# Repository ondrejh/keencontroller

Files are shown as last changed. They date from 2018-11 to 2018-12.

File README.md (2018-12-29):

# Keen Controller
Arduino micro based keyboard (mame controller) suitable for playing [Commander Keen](http://www.shikadi.net/keenwiki/Main_Page).

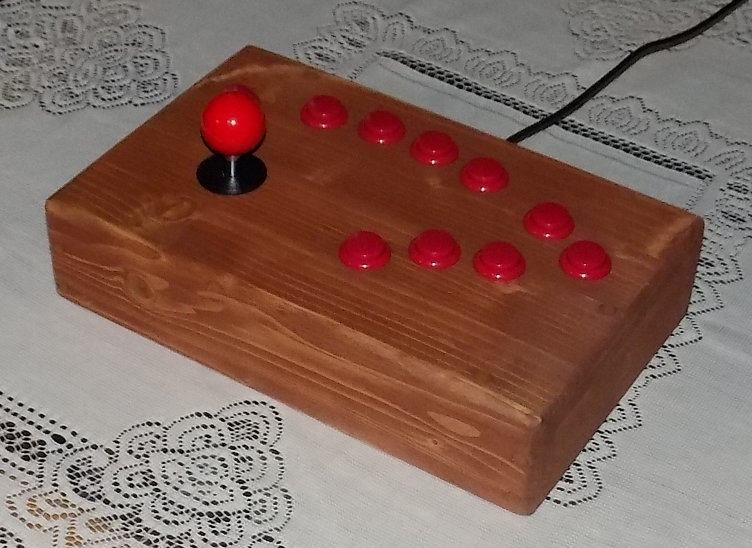
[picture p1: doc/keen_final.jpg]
Final product look


## The challenge:
Commander Keen looks like very good game for simple "few buttons" controller. Arrows, jump, fire .. that should be it. Well, its not. There are alot of "hidden" keys you need when not additional keyboard is available (for example in mame box). Finally, when using only joystick and 10 buttons, there are still some limitations like shared keys or limited save possitions.

## Project status:
The project is basically finished. The alternative keymaps for other games were added, multiple key was implemented, key sharing by rotating, ect.

- button model (learning freecad)
- all possible inputs of arduino covered now
- basic arduino program with 3 keys
- commander keen keymap
- wooden body
- dangerous dave and prince 2 keymaps

## BOM:

- [Arduino micro ATmega32U4](https://www.aliexpress.com/item/Free-Shipping-New-Pro-Micro-for-arduino-ATmega32U4-5V-16MHz-Module-with-2-row-pin-header/1348800135.html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,searchweb201602_5_10065_10068_319_317_10696_10084_453_454_10083_10618_10304_10307_10820_10821_538_537_10302_536_10059_10884_10887_100031_321_322_10103,searchweb201603_53,ppcSwitch_0&algo_expid=e6bf0f1d-14d2-4c70-9fee-68fe26168dd5-0&algo_pvid=e6bf0f1d-14d2-4c70-9fee-68fe26168dd5) Arduino Leonardo Pro Micro
- [10pcs 24mm arcade buttons](https://www.aliexpress.com/item/10-pcs-factory-price-arcade-button-24mm-Round-Push-Button-Built-in-small-micro-switch-for/32881608601.html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) 24mm button
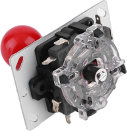
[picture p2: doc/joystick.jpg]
Joystick
- [Arcade joystick](https://www.aliexpress.com/item/Classic-Arcade-Joystick-4-8-way-DIY-Game-Joystick-Red-Ball-Fighting-Stick-Replacement-Parts-For/32571616716.html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) 
- Wood, glue, screws and resin
- Wires and solder

## Schematic (wire mess sketched on touchpad):

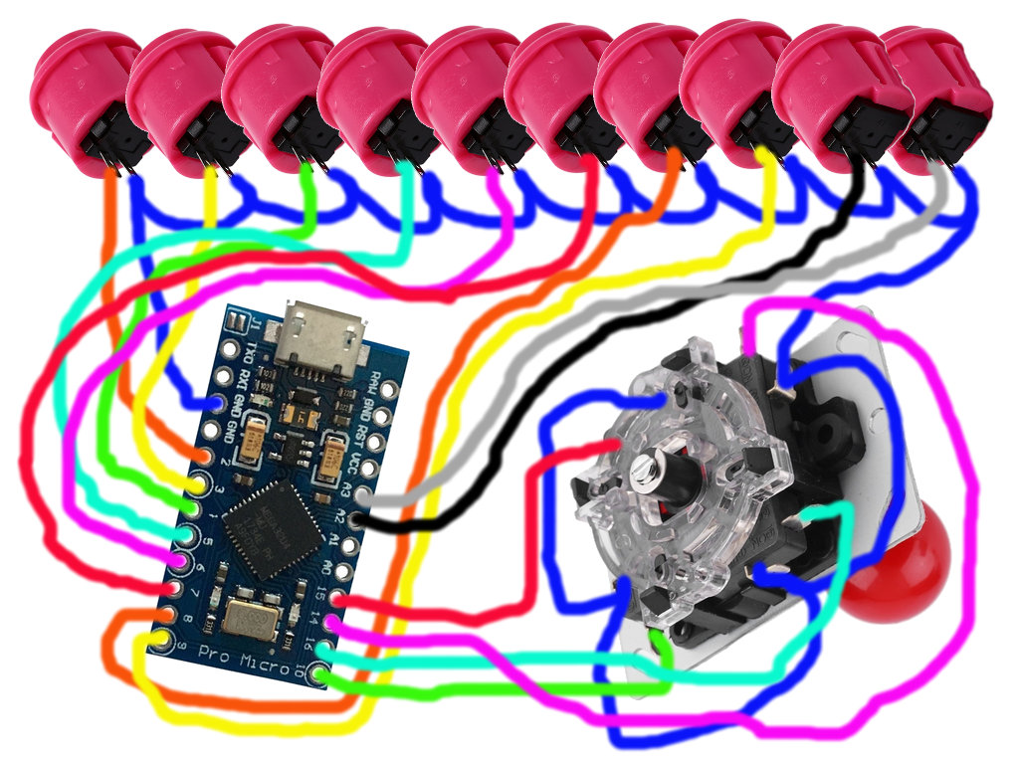
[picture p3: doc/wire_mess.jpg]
Schematic


## Keys needed (Commander Keen 1-3 / 4-6)
Arrows, ctrl, alt, esc, 1 - 9 (or at least some of those), y/t, n/d/enter ...

## Next steps:

1) Implement multiple keypress by queue (still not work).
2) Model (learn freecad, better).
3) Automatic keymap change (with some gui).

## Guts, if youre interested (wire mess hand soldered):

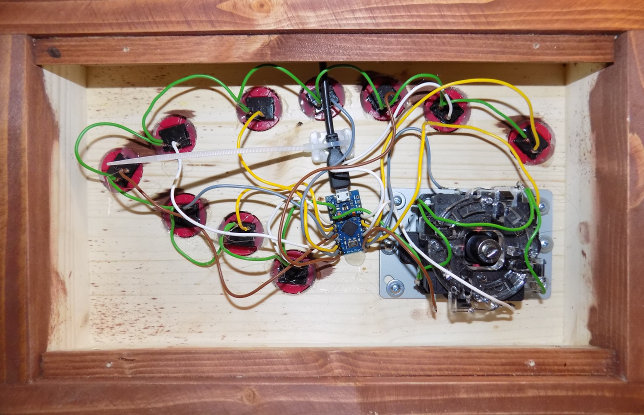
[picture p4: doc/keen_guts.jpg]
How it looks inside


## The End!

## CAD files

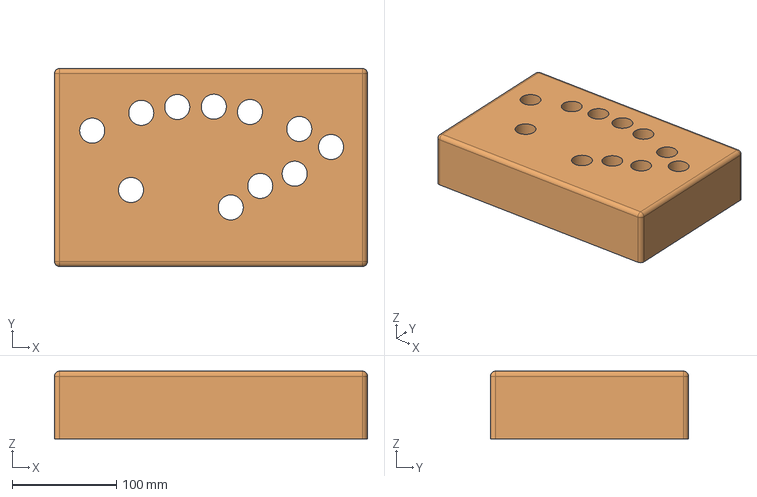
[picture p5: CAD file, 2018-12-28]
model/box.fcstd
300.0 x 190.0 x 65.0 mm

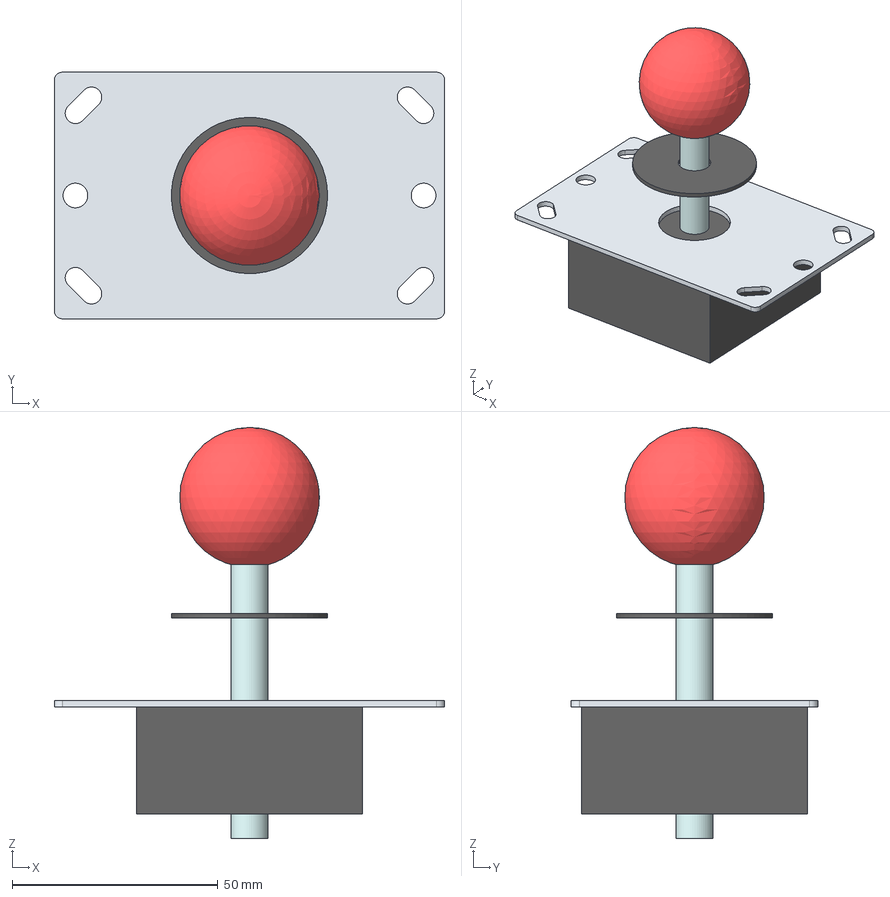
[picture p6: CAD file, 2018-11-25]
model/joystick.FCStd
95.0 x 60.0 x 100.0 mm
deska
krouzek
hridel
koule

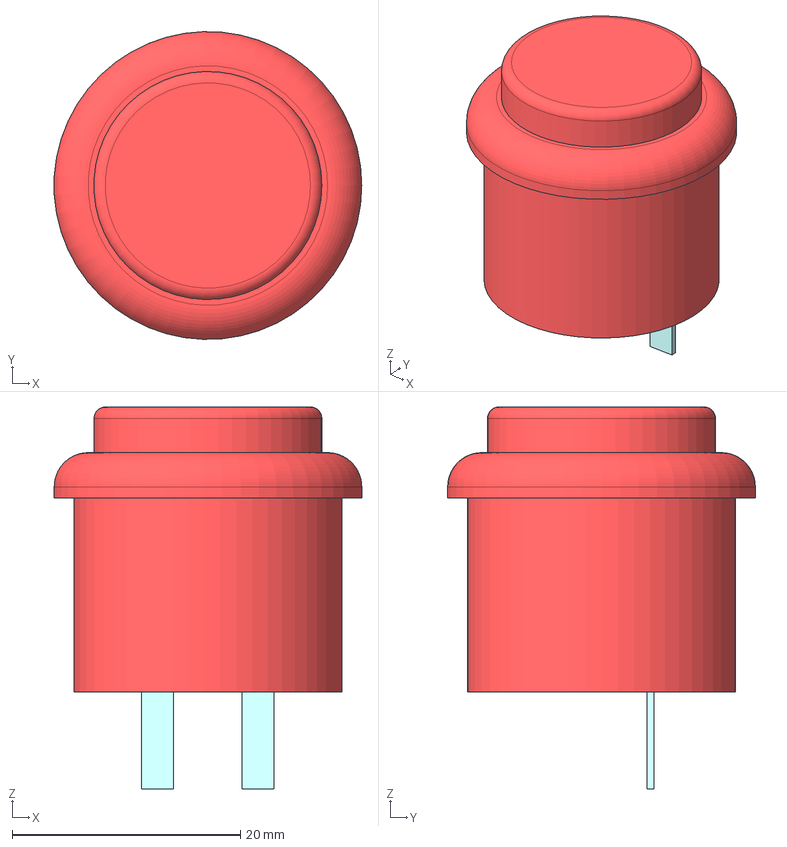
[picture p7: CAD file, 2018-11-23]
model/button.fcstd
27.0 x 27.0 x 33.5 mm
spodek
hmatnik_srazeni
okraj_srazeni
kontakt1
kontakt2

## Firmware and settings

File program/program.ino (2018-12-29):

/*
 Keyboard emulator for playing Commander Keen.

 For the Arduino Leonardo and Micro.

 The circuit:
 * set of pushbuttons and microswitch joystick attached from pin to GND.

 Original example code:
 created 24 Oct 2011
 modified 27 Mar 2012
 by Tom Igoe
 modified 11 Nov 2013
 by Scott Fitzgerald

 http://www.arduino.cc/en/Tutorial/KeyboardMessage

 modification to keencontroller (OH):
 started: 20.11.2018 - input settings, keyboard print tested
 first useful version: 3.12.2018 - multikey solved by rotating
 key function unified
 filter settings and keymaps moved into config.h
 */

#include "Keyboard.h"
#include "config.h"

// Filter
uint32_t flt_time;
uint8_t PBf[FILTER_LENGTH];
uint8_t PCf[FILTER_LENGTH];
uint8_t PDf[FILTER_LENGTH];
uint8_t PEf[FILTER_LENGTH];
uint8_t PFf[FILTER_LENGTH];
uint8_t Pp=0;
uint8_t PB=0, PC=0, PD=0, PE=0, PF=0;

// PORT MASKS

// PORTB (--- D10 D09 D08 D14 D16 D15 ---)
#define D08 (1<<4)
#define D09 (1<<5)
#define D10 (1<<6)
#define D14 (1<<3)
#define D15 (1<<1)
#define D16 (1<<2)
#define PORTB_MASK (D15 | D16 | D14 | D08 | D09 | D10)

// PORTC (--- D05 --- --- --- --- --- ---)
#define D05 (1<<6)
#define PORTC_MASK (D05)

// PORTD (D06 --- --- D04 --- --- D02 D03)
#define D02 (1<<1)
#define D03 (1<<0)
#define D04 (1<<4)
#define D06 (1<<7)
#define PORTD_MASK (D03 | D02 | D04 | D06)

// PORTE (--- D07 --- --- --- --- --- ---)
#define D07 (1<<6)
#define PORTE_MASK (D07)

// PORTF (A00 A01 A02 A03 --- --- --- ---)
#define A00 (1<<7)
#define A01 (1<<6)
#define A02 (1<<5)
#define A03 (1<<4)
#define PORTF_MASK (A03 | A02 | A01 | A00)

uint8_t pB = PORTB_MASK, pC = PORTC_MASK, pD = PORTD_MASK, pE = PORTE_MASK, pF = PORTF_MASK;

uint8_t rotCnt[16];

#define QUE_PRESS_TIME 200
#define QUE_RELEASE_TIME 100
#define QUELEN 16
uint8_t queue[QUELEN];
uint8_t quein = 0;
uint8_t queout = 0;
uint8_t questatus = 0;
unsigned long quetime = 0;

void que_insert(uint8_t key) {
  uint8_t next = quein + 1;
  next %= QUELEN;
  if (next != queout) {
    queue[quein] = key;
    quein = next;
  }
}

void key_set(bool stat, uint8_t *rot, const uint8_t *key) {
  if (key[0] == 0) // 0 keys to press .. do nothing
    return;
    
  switch (key[0] & 0xF0) { // select key type
    
  case KT_FST: // fast key(s)
    if (stat)
      for (int i = (key[0] & 0x0F); i > 0; i--)
        Keyboard.release(key[i]);
    else
      for (int i = 1; i <= (key[0] & 0x0F); i++)
        Keyboard.press(key[i]);
    break;
    
  case KT_ROT: // rotate (changing) keys
    if (*rot == 0)
      *rot = 1;
    if (stat) {
      Keyboard.release(key[*rot]);
      *rot += 1;
      if (*rot > (key[0] & 0x0F))
        *rot = 1;
    }
    else
      Keyboard.press(key[*rot]);
    break;

  case KT_QUE: // queue
    for (int i=1; i<=key[0]&0x0F; i++) {
      que_insert(key[i]);
    }
    break;

  default: // unknown type, do nothing
    break;
  }
}

void setup() {
  // make the pushButton nibbles an input with pullup:
  DDRB |= PORTB_MASK;
  PORTB |= PORTB_MASK;

  DDRC |= PORTC_MASK;
  PORTC |= PORTC_MASK;

  DDRD |= PORTD_MASK;
  PORTD |= PORTD_MASK;

  DDRE |= PORTE_MASK;
  PORTE |= PORTE_MASK;

  DDRF |= PORTF_MASK;
  PORTF |= PORTF_MASK;

  memset(rotCnt, 0, 16);

  // initialize control over the keyboard:
  Keyboard.begin();
}

void loop() {
  uint8_t p, px;

  uint32_t now = millis();
  if ((flt_time-now) >= FILTER_TIME_MS)
  {
    flt_time = now;

    // read inputs
    PBf[Pp] = PINB & PORTB_MASK;
    PCf[Pp] = PINC & PORTC_MASK;
    PDf[Pp] = PIND & PORTD_MASK;
    PEf[Pp] = PINE & PORTE_MASK;
    PFf[Pp] = PINF & PORTF_MASK;
    Pp ++;
    Pp %= FILTER_LENGTH;

    // discover changing bits
    uint8_t chB=0, chC=0, chD=0, chE=0, chF=0;
    for (int i=1; i<FILTER_LENGTH; i++) {
      chB |= PBf[0] ^ PBf[i];
      chC |= PCf[0] ^ PCf[i];
      chD |= PDf[0] ^ PDf[i];
      chE |= PEf[0] ^ PEf[i];
      chF |= PFf[0] ^ PFf[i];
    }

    // copy stable bits into output
    PB = (PB & chB) | (PBf[0] & ~chB);
    PC = (PC & chC) | (PCf[0] & ~chC);
    PD = (PD & chD) | (PDf[0] & ~chD);
    PE = (PE & chE) | (PEf[0] & ~chE);
    PF = (PF & chF) | (PFf[0] & ~chF);
  }
  
  // PORT B
  p = PB;//PINB & PORTB_MASK;
  px = pB ^ p;
  if (px & D08) key_set(p & D08, &rotCnt[0], D08_KEYS);
  if (px & D09) key_set(p & D09, &rotCnt[1], D09_KEYS);
  if (px & D10) key_set(p & D10, &rotCnt[2], D10_KEYS);
  if (px & D14) key_set(p & D14, &rotCnt[3], D14_KEYS);
  if (px & D15) key_set(p & D15, &rotCnt[4], D15_KEYS);
  if (px & D16) key_set(p & D16, &rotCnt[5], D16_KEYS);
  pB = p;

  // PORT C
  p = PC;//PINC & PORTC_MASK;
  px = pC ^ p;
  //if (px & D05) multikey_set(p & D07, &d05_kp, D05_KEYS);
  if (px & D05) key_set(p & D07, &rotCnt[6], D05_KEYS);
  pC = p;
  
  // PORT D
  p = PD;//PIND & PORTD_MASK;
  px = pD ^ p;
  if (px & D02) key_set(p & D02, &rotCnt[7], D02_KEYS);
  if (px & D03) key_set(p & D03, &rotCnt[6], D03_KEYS);
  if (px & D04) key_set(p & D04, &rotCnt[8], D04_KEYS);
  //if (px & D06) multikey_set(p & D06, &d06_kp, D06_KEYS);
  if (px & D06) key_set(p & D06, &rotCnt[9], D06_KEYS);
  pD = p;

  // PORT E
  p = PE;//PINE & PORTE_MASK;
  px = pE ^ p;
  if (px & D07) key_set(p & D07, &rotCnt[10], D07_KEYS);
  pE = p;

  // PORT F
  p = PF;//PINF & PORTF_MASK;
  px = pF ^ p;
  if (px & A00) key_set(p & A00, &rotCnt[11], A00_KEYS);
  if (px & A01) key_set(p & A01, &rotCnt[12], A01_KEYS);
  if (px & A02) key_set(p & A02, &rotCnt[13], A02_KEYS);
  if (px & A03) key_set(p & A03, &rotCnt[14], A03_KEYS);
  pF = p;

  switch (questatus) {
  case 0:
    if (quein!=queout) {
      Keyboard.press(queue[queout]);
      quetime = now;
      questatus++;
    }
    break;
  case 1:
    if ((now - quetime) >= QUE_PRESS_TIME) {
      Keyboard.release(queue[queout]);
      int next = (queout + 1) % QUELEN;
      queout = next;
      quetime = now;
      questatus++;
    }
    break;
  case 2:
    if ((now - quetime) >= QUE_RELEASE_TIME) {
      questatus=0;
    }
    break;
  default:
    questatus = 0;
    break;
  }
}

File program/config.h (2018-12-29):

#ifndef __CONFIG_H__
#define __CONFIG_H__

#define KEEN
//#define DAVE
//#define PRINCE2

// Filter
#define FILTER_TIME_MS 1
#define FILTER_LENGTH 3

// KEY TYPE
#define KT_FST 0x00
#define KT_ROT 0x10
#define KT_QUE 0x20

// keymap Commander Keen
#ifdef KEEN
const uint8_t D02_KEYS[2] = {KT_FST + 1, ' '};
const uint8_t D03_KEYS[2] = {KT_FST + 1, KEY_LEFT_CTRL};
const uint8_t D04_KEYS[2] = {KT_FST + 1, KEY_LEFT_ALT};
const uint8_t D05_KEYS[4] = {KT_ROT + 3, 'd', 'y', KEY_RETURN};
const uint8_t D06_KEYS[4] = {KT_ROT + 3, 't', 'n', KEY_F5};
const uint8_t D07_KEYS[2] = {KT_FST + 1, '4'};
const uint8_t D08_KEYS[2] = {KT_FST + 1, '3'};
const uint8_t D09_KEYS[2] = {KT_FST + 1, '2'};
const uint8_t D10_KEYS[2] = {KT_FST + 1, KEY_LEFT_ARROW};
const uint8_t D14_KEYS[2] = {KT_FST + 1, KEY_RIGHT_ARROW};
const uint8_t D15_KEYS[2] = {KT_FST + 1, KEY_UP_ARROW};
const uint8_t D16_KEYS[2] = {KT_FST + 1, KEY_DOWN_ARROW};
const uint8_t A00_KEYS[1] = {0};
const uint8_t A01_KEYS[1] = {0};
const uint8_t A02_KEYS[2] = {KT_FST + 1, KEY_ESC};
const uint8_t A03_KEYS[2] = {KT_FST + 1, '1'};
#endif

// keymap Dangerous Dave
#ifdef DAVE
const uint8_t D02_KEYS[2] = {KT_FST + 1, KEY_LEFT_ALT};
const uint8_t D03_KEYS[2] = {KT_FST + 1, ' ' };
const uint8_t D04_KEYS[2] = {KT_FST + 1, KEY_TAB};
const uint8_t D05_KEYS[2] = {KT_FST + 1, 'y'};
const uint8_t D06_KEYS[2] = {KT_FST + 1, 'n'};
const uint8_t D07_KEYS[1] = {0};
const uint8_t D08_KEYS[1] = {0};
const uint8_t D09_KEYS[1] = {0};
const uint8_t D10_KEYS[2] = {KT_FST + 1, KEY_LEFT_ARROW};
const uint8_t D14_KEYS[2] = {KT_FST + 1, KEY_RIGHT_ARROW};
const uint8_t D15_KEYS[2] = {KT_FST + 1, KEY_UP_ARROW};
const uint8_t D16_KEYS[2] = {KT_FST + 1, KEY_DOWN_ARROW};
const uint8_t A00_KEYS[1] = {0};
const uint8_t A01_KEYS[1] = {0};
const uint8_t A02_KEYS[2] = {KT_FST + 1, KEY_ESC};
const uint8_t A03_KEYS[1] = {0};
#endif

// keymap Prince 2
#ifdef PRINCE2
const uint8_t D02_KEYS[2] = {KT_FST + 1, KEY_UP_ARROW};
const uint8_t D03_KEYS[2] = {KT_FST + 1, KEY_LEFT_CTRL};
const uint8_t D04_KEYS[2] = {KT_FST + 1, KEY_LEFT_SHIFT};
const uint8_t D05_KEYS[2] = {KT_FST + 1, KEY_RETURN};
const uint8_t D06_KEYS[2] = {KT_FST + 1, KEY_ESC};
const uint8_t D07_KEYS[3] = {KT_FST + 2, KEY_LEFT_ALT, 'O'};
const uint8_t D08_KEYS[3] = {KT_FST + 2, KEY_LEFT_CTRL, 'A'};
const uint8_t D09_KEYS[3] = {KT_FST + 2, KEY_LEFT_CTRL, 'S'};
const uint8_t D10_KEYS[2] = {KT_FST + 1, KEY_LEFT_ARROW};
const uint8_t D14_KEYS[2] = {KT_FST + 1, KEY_RIGHT_ARROW};
const uint8_t D15_KEYS[2] = {KT_FST + 1, KEY_UP_ARROW};
const uint8_t D16_KEYS[2] = {KT_FST + 1, KEY_DOWN_ARROW};
const uint8_t A00_KEYS[1] = {0};
const uint8_t A01_KEYS[1] = {0};
const uint8_t A02_KEYS[3] = {KT_FST + 2, KEY_LEFT_CTRL, 'Q'};
const uint8_t A03_KEYS[3] = {KT_FST + 2, KEY_LEFT_CTRL, 'S'};
#endif

#endif __CONFIG_H__

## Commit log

2018-11-23 button model
    [button.fcstd]
2018-11-23 joystick plate
    [button.fcstd, joystick.FCStd]
2018-11-23 joystick, 2nd try
    [joystick.FCStd, joystick2trial.FCStd]
2018-12-04 multikey solved by cycling
    [program.ino]
2018-12-09 queue tested, doesn't work well - back to rotate
    [program.ino]
2018-12-27 functional filter (finally)
2018-12-28 model update
    [box.fcstd]
